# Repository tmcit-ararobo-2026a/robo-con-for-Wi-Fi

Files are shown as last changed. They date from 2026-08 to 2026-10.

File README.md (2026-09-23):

# < robo-con-for-Wi-Fi >

<!-- 一行でプロジェクトを説明する -->
the code and pcb in this repository is wireless robot's controller.     

## 目次

1. [概要](#1-概要)
2. [ドキュメント](#2-ドキュメント)
3. [コントリビューション](#3-コントリビューション)
4. [ビルド・使い方](#4-ビルド使い方)
5. [システム構成](#5-システム構成)
6. [ライセンス](#6-ライセンス)

## 1. 概要

<!-- プロジェクトの目的・背景・解決する課題を記述 -->
ロボコンなどの会場のなかでは2.4GHzもしくは5GHzといった周波数帯は多くの場合かなり混雑していることが多い。    
こういった大会で無線による有利は勝敗に大きく作用するため、使用する周波数はできるだけ混雑していないことが望ましい。  
そのため、6GHzを使うコントローラーを作成する。  

## 2. ドキュメント

| ドキュメント | 説明 |
| :-: | :-: |
| [CONTRIBUTING.md](./CONTRIBUTING.md) | 開発フロー・コミット規約・コーディング規約 |
| [docs/coding-rules.md](./docs/coding-rules.md) | コーディング規約の詳細 |
| [docs/uml/](./docs/uml/) | UML図 |

## 3. コントリビューション

[CONTRIBUTING.md](./CONTRIBUTING.md) を参照してください。

## 4. ビルド・使い方

<!-- ビルドのやり方 -->
<!-- 使い方 -->

## 5. システム構成

<!-- ROS2ノード構成・STM32との通信方式・ハードウェア構成 等 -->
<!-- 依存クラスが3つ以上ある場合は docs/uml/ にUML図を作成し、ここにリンクする -->

## 6. ライセンス

本リポジトリは [MITライセンス](./LICENSE) のもとで公開されています。

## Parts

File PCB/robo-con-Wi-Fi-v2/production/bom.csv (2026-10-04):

Designator | Footprint | Quantity | Value | LCSC Part #
C12, C13, C14, C15, C16, C17, C18, C19, C28, C33, C50, C66, C68, C69, C70, C72, C73, C78 | 0402 | 18 | 0.1u
C30, C31 | 0402 | 2 | 2.2u
C34, C35 | 0402 | 2 | 18pF
C61, C71, C80 | 0402 | 3 | 1u
C62, C63, C64, C74, C75, C76, C77, C79, C81, C83 | 0402 | 10 | 4.7u
C65 | 0402 | 1 | 1n
C82 | 0603 | 1 | 10u
D1 | 0603 | 1 | R
D10, D13, D14, D17 | 0603 | 4 | O
D11, D12 | 0603 | 2 | W
D16, D3 | 0603 | 2 | G
D5 | 0603 | 1 | B
F1 | 0603 | 1 | FHC16322ADTP
J1 | PinSocket_1x04_P2.54mm_Vertical | 1 | Conn_01x04
J11, J3 | JST_ZH_B5B-ZR_1x05_P1.50mm_Vertical | 2 | Conn_01x05
J2 | SMA_Conn | 1 | SMA-J
J4, J6, J8, J9 | SolderWirePad_1x01_SMD_1.5x3mm | 4 | Conn_01x01
J5 | JST_PH_S2B-PH-K_1x02_P2.00mm_Horizontal | 1 | Conn_01x02
L1 | 1008 | 1 | 2.2u
R11, R2, R21, R25, R32, R33, R34, R35, R37, R38, R4, R43, R45, R46, R6 | 0402 | 15 | 1k
R23 | 0402 | 1 | 10k
R24 | 0603 | 1 | 2.2k
R26, R27 | 0603 | 2 | 1k
R3, R5 | 0402 | 2 | 22
R39, R40 | 0402 | 2 | 4.7k
R41 | 0603 | 1 | 100k
R44 | WA04X102 | 1 | WA04X102
SW1 | switch_TVAF06-A020B-R | 1 | SW_Push
SW3, SW4 | SKHHLPA010 | 2 | SW_Push
SW5 | 4MS1R202M6QES | 1 | SW_Push_SPDT
SW6, SW7 | 8MS8P1B05VS2QES-C13 | 2 | SW_Push_SPDT
U10 | SOT-23-5 | 1 | MCP73831-2-OT
U11, U15 | SOT-363_SC-70-6 | 2 | LM66100DCK
U18 | USB_C_Receptacle_Nelton_5077CR-16-SMC2-BK-TR | 1 | USB_Type-C
U2 | LBEE5HY2FY | 1 | LBEE5HY2FY
U3 | WDFN-12-1EP_3x3mm_P0.45mm_EP1.7x2.5mm | 1 | FT234XD
U4 | DFN-8-1EP_3x3mm_P0.65mm_EP1.55x2.4mm | 1 | MCP1727-1802xMF
U5, U7 | RKJXV122400R | 2 | RKJXV122400R
U6 | DFN-6-1EP_3x3mm_P0.95mm_EP1.7x2.6mm | 1 | LD39200PU33R
U8 | LQFP-64_10x10mm_P0.5mm | 1 | STM32H7A3RGTx
Y2 | XRCGB25M000FFS1AR0 | 1 | XRCGB25M000FFS1AR0

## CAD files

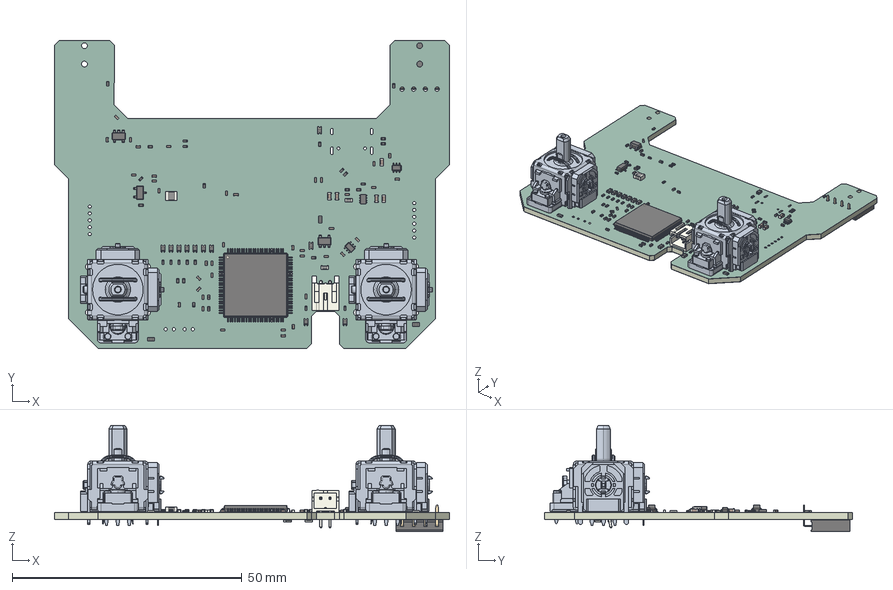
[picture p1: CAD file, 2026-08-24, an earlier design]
PCB/robo-con-Wi-Fi/動いたら使うやつ.step
86.0 x 67.0 x 23.2 mm
R_0402_1005Metric x 27
C_0402_1005Metric x 41
C_0603_1608Metric x 5
SC-59
D_0603_1608Metric x 11
SOT-583-8
R_0603_1608Metric x 5
.step 1.40 x 2
JST_PH_S2B-PH-K_1x02_P2.00mm_Horizontal
L_0603_1608Metric x 2
SOT-363_SC-70-6 x 2
L_1008_2520Metric
LQFP-100_14x14mm_P0.5mm
SOT-23-5 x 2
PinSocket_1x04_P2.54mm_Horizontal
robo-con-Wi-Fi_soldermask x 2
robo-con-Wi-Fi_PCB

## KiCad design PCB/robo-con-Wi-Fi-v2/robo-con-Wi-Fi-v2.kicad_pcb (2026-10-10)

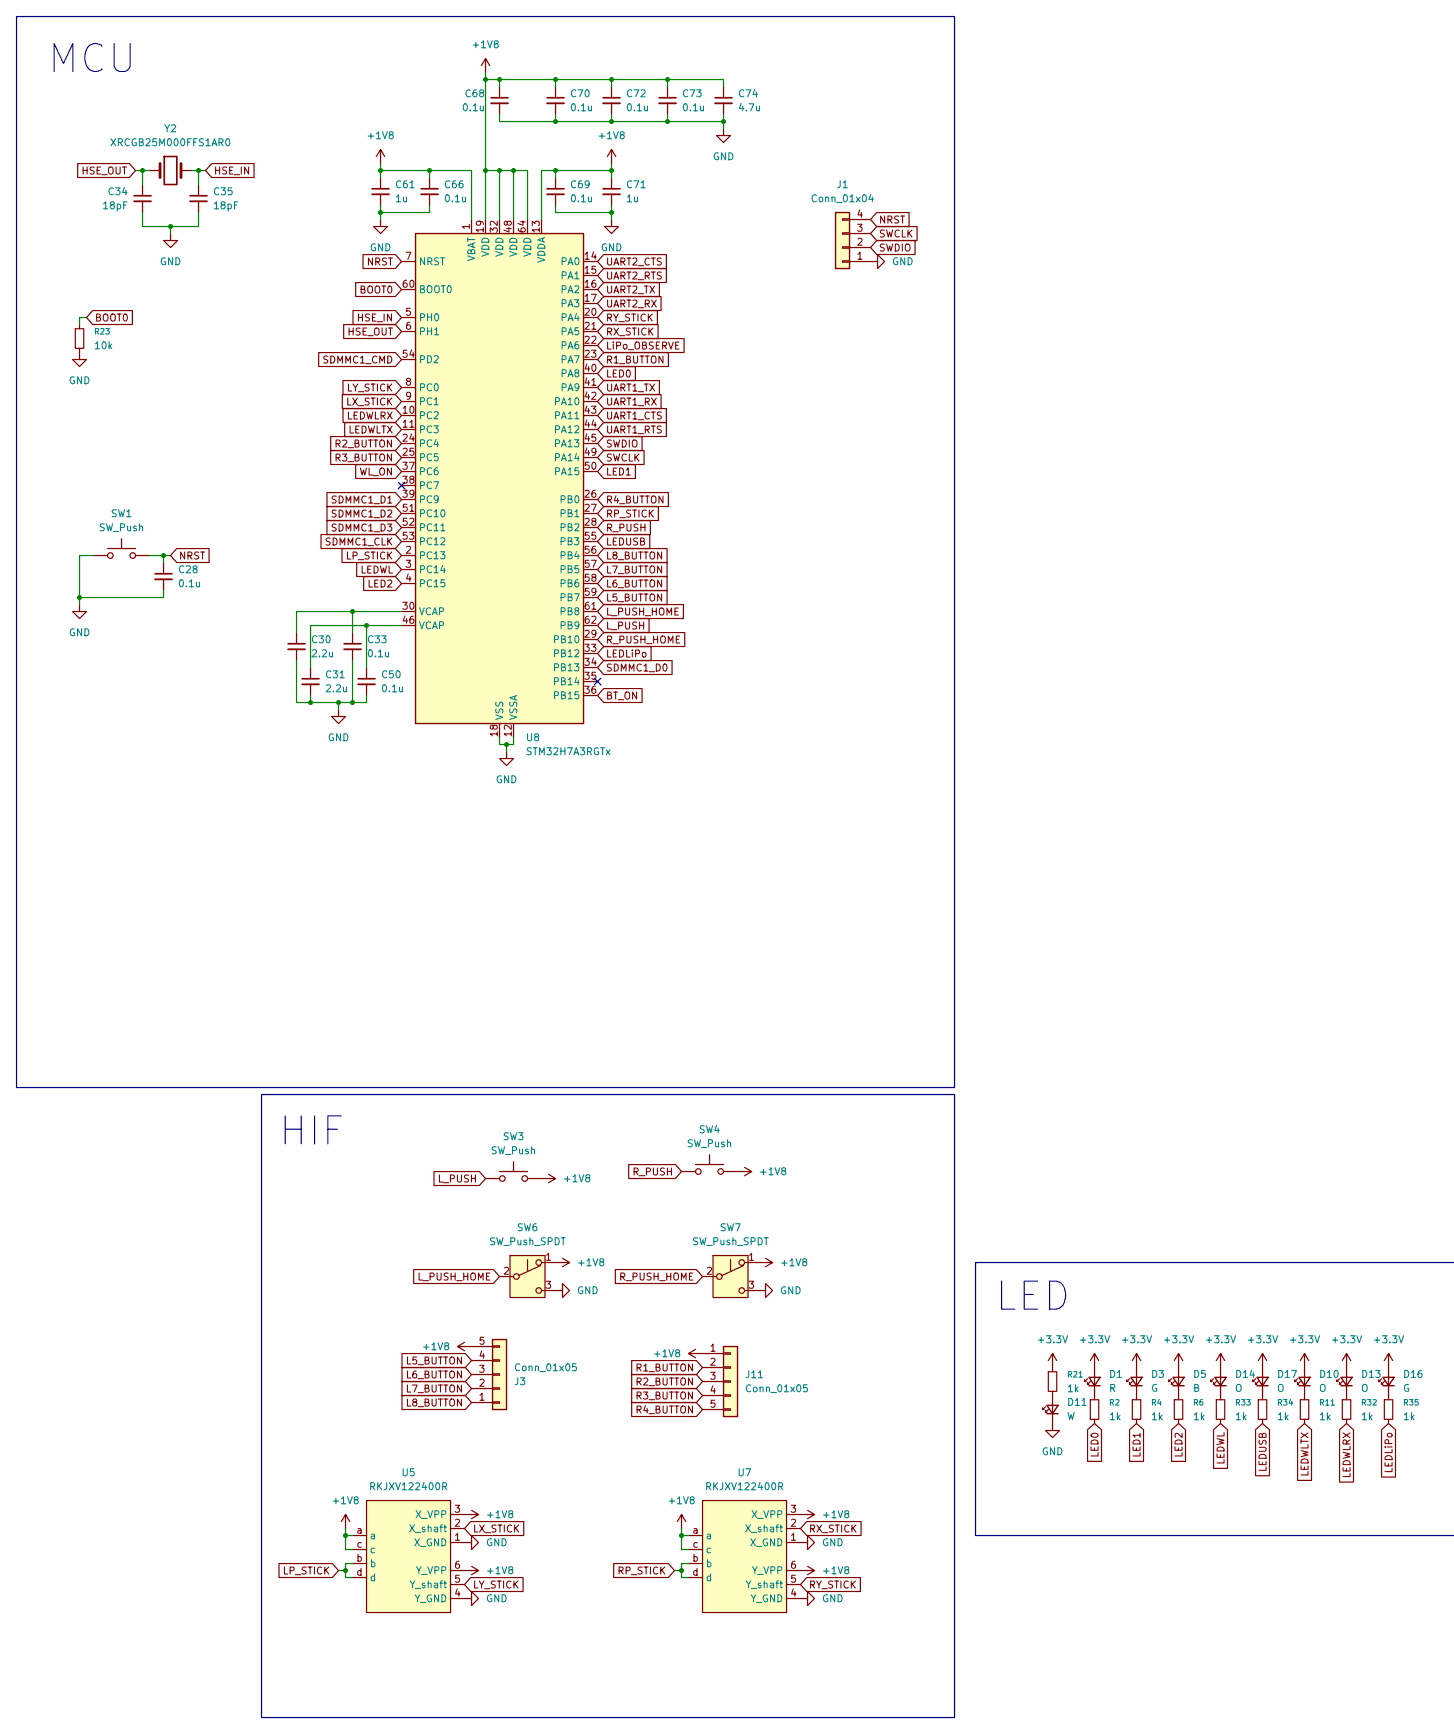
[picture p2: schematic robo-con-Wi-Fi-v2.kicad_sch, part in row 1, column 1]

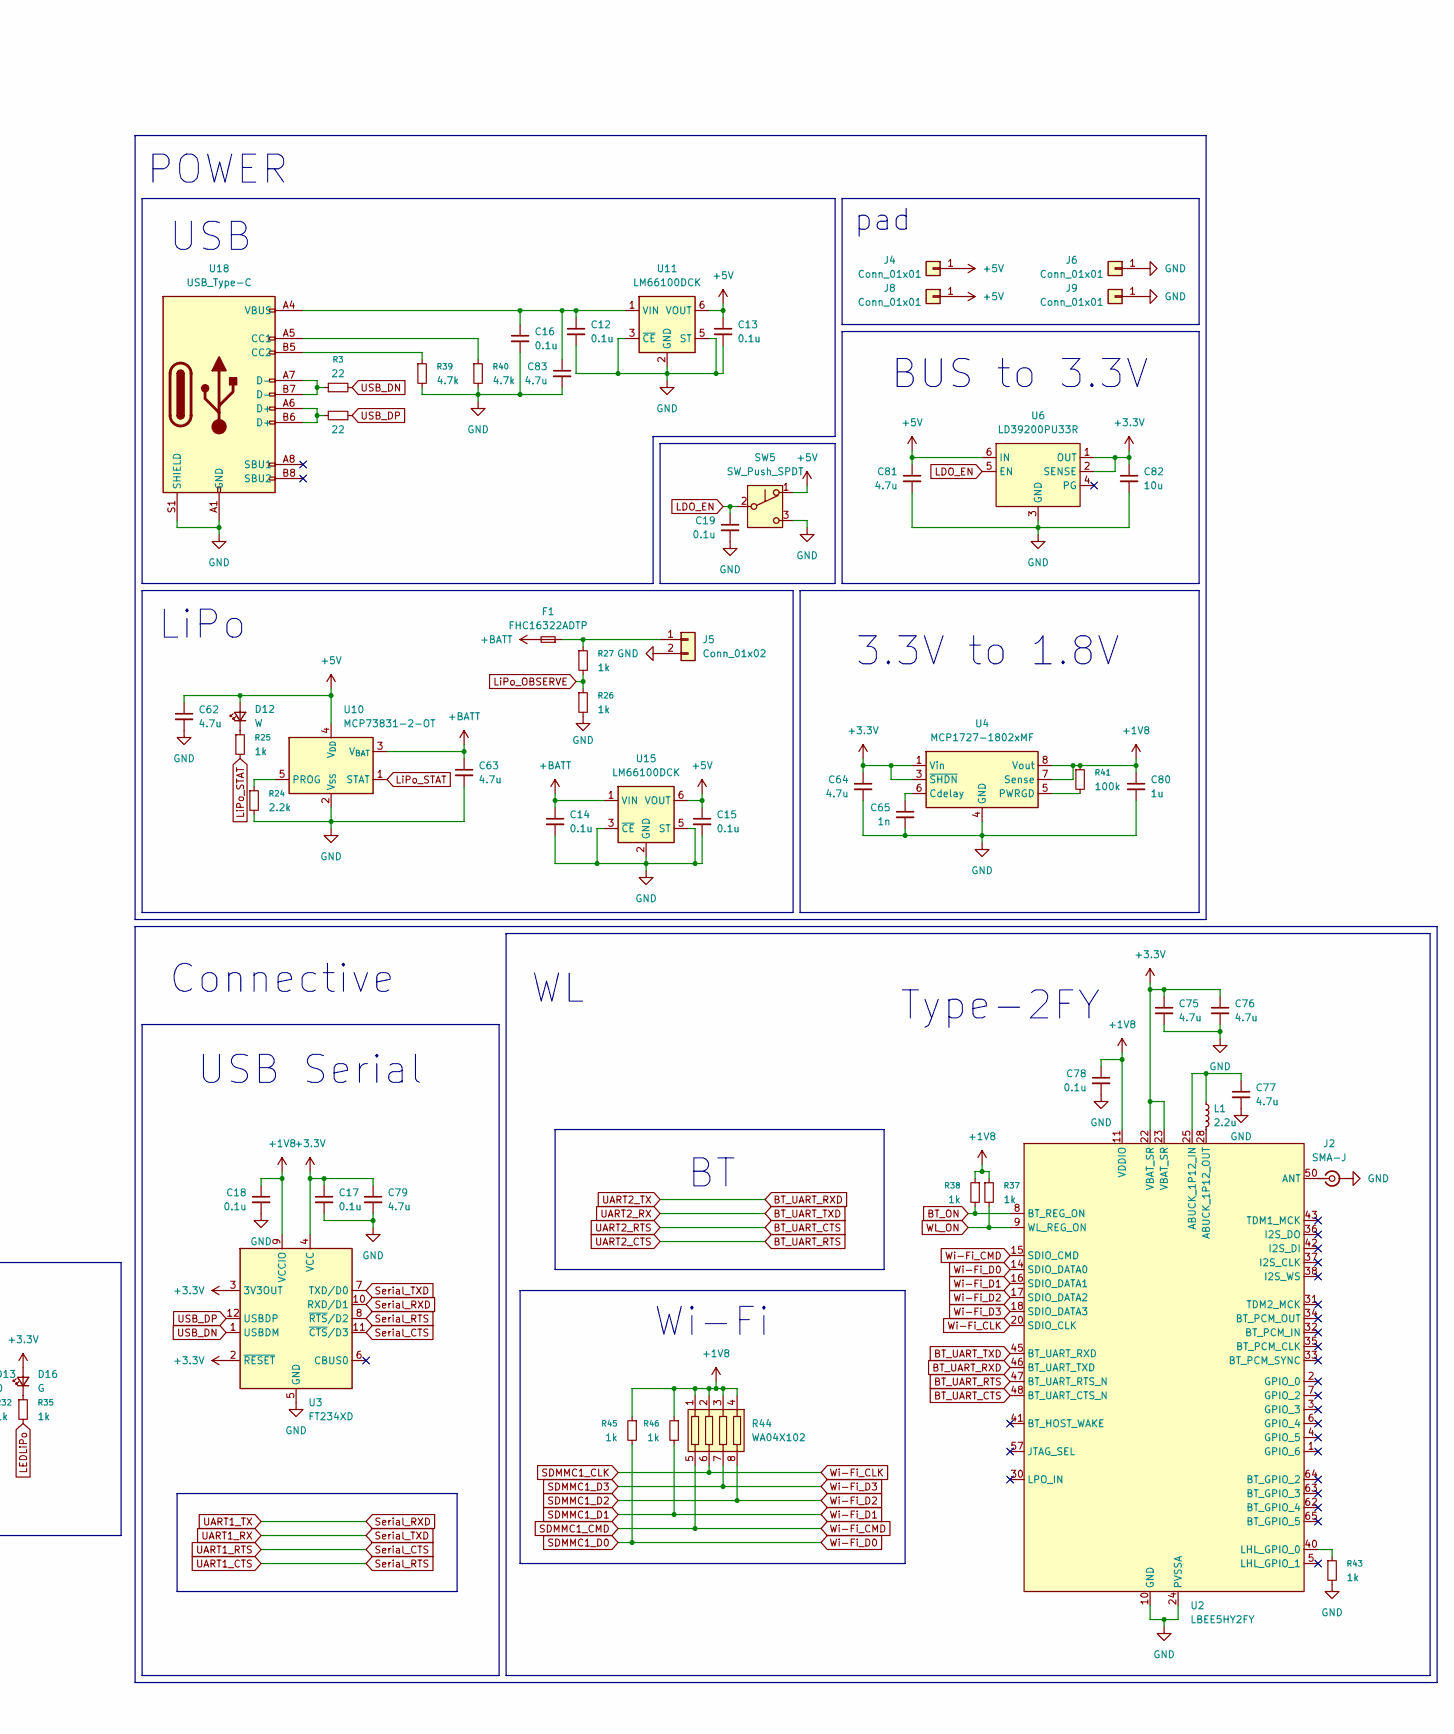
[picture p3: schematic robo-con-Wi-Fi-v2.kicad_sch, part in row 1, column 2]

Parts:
C12, C13, C14, C15, C16, C17, C18, C19, C28, C33, C50, C66, C68, C69, C70, C72, C73, C78: 0.1u; C_0402_1005Metric_Pad0.74x0.62mm_HandSolder
C30, C31: 2.2u; C_0402_1005Metric_Pad0.74x0.62mm_HandSolder
C34, C35: 18pF; C_0402_1005Metric_Pad0.74x0.62mm_HandSolder
C61, C71, C80: 1u; C_0402_1005Metric_Pad0.74x0.62mm_HandSolder
C62, C63, C64, C74, C75, C76, C77, C79, C81, C83: 4.7u; C_0402_1005Metric_Pad0.74x0.62mm_HandSolder
C65: 1n; C_0402_1005Metric_Pad0.74x0.62mm_HandSolder
C82: 10u; C_0603_1608Metric_Pad1.08x0.95mm_HandSolder
D1: R; D_0603_1608Metric_Pad1.05x0.95mm_HandSolder
D3, D16: G; D_0603_1608Metric_Pad1.05x0.95mm_HandSolder
D5: B; D_0603_1608Metric_Pad1.05x0.95mm_HandSolder
D10, D13, D14, D17: O; D_0603_1608Metric_Pad1.05x0.95mm_HandSolder
D11, D12: W; D_0603_1608Metric_Pad1.05x0.95mm_HandSolder
F1: FHC16322ADTP; L_0603_1608Metric_Pad1.05x0.95mm_HandSolder
J1: Conn_01x04; PinSocket_1x04_P2.54mm_Vertical
J2: SMA-J; SMA_Conn
J3, J11: Conn_01x05; JST_ZH_B5B-ZR_1x05_P1.50mm_Vertical
J4, J6, J8, J9: Conn_01x01; SolderWirePad_1x01_SMD_1.5x3mm
J5: Conn_01x02; JST_PH_S2B-PH-K_1x02_P2.00mm_Horizontal
L1: 2.2u; L_1008_2520Metric_Pad1.43x2.20mm_HandSolder
R2, R4, R6, R11, R21, R25, R32, R33, R34, R35, R37, R38, R43, R45, R46: 1k; R_0402_1005Metric_Pad0.72x0.64mm_HandSolder
R3, R5: 22; R_0402_1005Metric_Pad0.72x0.64mm_HandSolder
R23: 10k; R_0402_1005Metric_Pad0.72x0.64mm_HandSolder
R24: 2.2k; R_0603_1608Metric_Pad0.98x0.95mm_HandSolder
R26, R27: 1k; R_0603_1608Metric_Pad0.98x0.95mm_HandSolder
R39, R40: 4.7k; R_0402_1005Metric_Pad0.72x0.64mm_HandSolder
R41: 100k; R_0603_1608Metric_Pad0.98x0.95mm_HandSolder
R44: WA04X102
SW1: SW_Push; switch_TVAF06-A020B-R
SW3, SW4: SW_Push; SKHHLPA010
SW5: SW_Push_SPDT; 4MS1R202M6QES
SW6, SW7: SW_Push_SPDT; 8MS8P1B05VS2QES-C13
U2: LBEE5HY2FY
U3: FT234XD; WDFN-12-1EP_3x3mm_P0.45mm_EP1.7x2.5mm
U4: MCP1727-1802xMF; DFN-8-1EP_3x3mm_P0.65mm_EP1.55x2.4mm
U5, U7: RKJXV122400R
U6: LD39200PU33R; DFN-6-1EP_3x3mm_P0.95mm_EP1.7x2.6mm
U8: STM32H7A3RGTx; LQFP-64_10x10mm_P0.5mm
U10: MCP73831-2-OT; SOT-23-5
U11, U15: LM66100DCK; SOT-363_SC-70-6
U18: USB_Type-C; USB_C_Receptacle_Nelton_5077CR-16-SMC2-BK-TR
Y2: XRCGB25M000FFS1AR0

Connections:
+1V8: C18.1, C61.1, C66.1, C68.1, C69.1, C70.1, C71.1, C72.1, C73.1, C74.1, C78.1, C80.1, J3.5, J11.1, R37.1, R38.1, R41.1, R44.1, R44.2, R44.3, R44.4, R45.1, R46.1, SW3.2, SW4.2, SW6.1 (A), SW7.1 (A), U2.11 (VDDIO), U3.9 (VCCIO), U4.7 (Sense), U4.8 (Vout), U5.3 (X_VPP), U5.6 (Y_VPP), U5.a, U5.c, U7.3 (X_VPP), U7.6 (Y_VPP), U7.a, U7.c, U8.1 (VBAT), U8.13 (VDDA), U8.19 (VDD), U8.32 (VDD), U8.48 (VDD), U8.64 (VDD)
+3.3V: C17.1, C64.1, C75.1, C76.1, C79.1, C82.1, D1.2 (A), D3.2 (A), D5.2 (A), D10.2 (A), D13.2 (A), D14.2 (A), D16.2 (A), D17.2 (A), R21.1, U2.22 (VBAT_SR), U2.23 (VBAT_SR), U3.2 (~RESET), U3.3 (3V3OUT), U3.4 (VCC), U4.1 (Vin), U4.2 (Vin), U4.3 (~SHDN), U6.1 (OUT), U6.2 (SENSE)
+5V: C13.1, C15.1, C62.1, C81.1, D12.2 (A), J4.1 (Pin_1_1), J8.1 (Pin_1_1), SW5.1 (A), U6.6 (IN), U10.4 (V_{DD}), U11.6 (VOUT), U15.6 (VOUT)
+BATT: C14.1, C63.1, F1.2, U10.3 (V_{BAT}), U15.1 (VIN)
BOOT0: R23.1, U8.60 (BOOT0)
BT_ON: R38.2, U2.8 (BT_REG_ON), U8.36 (PB15)
BT_UART_CTS: U2.48 (BT_UART_CTS_N), U8.15 (PA1)
BT_UART_RTS: U2.47 (BT_UART_RTS_N), U8.14 (PA0)
BT_UART_RXD: U2.46 (BT_UART_TXD), U8.16 (PA2)
BT_UART_TXD: U2.45 (BT_UART_RXD), U8.17 (PA3)
GND: C12.2, C13.2, C14.2, C15.2, C16.2, C17.2, C18.2, C19.2, C28.2, C30.2, C31.2, C33.2, C34.2, C35.2, C50.2, C61.2, C62.2, C63.2, C64.2, C65.2, C66.2, C68.2, C69.2, C70.2, C71.2, C72.2, C73.2, C74.2, C75.2, C76.2, C77.2, C78.2, C79.2, C80.2, C81.2, C82.2, C83.2, D11.1 (K), J1.1, J2.2 (Ext), J5.2, J6.1 (Pin_1_1), J9.1 (Pin_1_1), R23.2, R24.2, R26.2, R39.2, R40.2, R43.2, SW1.1, SW5.3 (C), SW6.3 (C), SW7.3 (C), U2.10 (GND), U2.12 (GND), U2.13 (GND), U2.19 (GND), U2.21 (GND), U2.24 (PVSSA), U2.26 (PVSSA), U2.27 (PVSSA), U2.29 (GND), U2.39 (GND), U2.44 (GND), U2.49 (GND), U2.51 (GND), U2.52 (GND), U2.53 (GND), U2.55 (GND), U2.56 (GND), U2.58 (GND), U2.59 (GND), U2.60 (GND), U2.61 (GND), U2.66 (GND), U2.67 (GND), U2.68 (GND), U2.69 (GND), U2.70 (GND), U2.71 (GND), U2.72 (GND), U3.5 (GND), U3.13 (GND), U4.4 (GND), U4.9 (GND), U5.1 (X_GND), U5.4 (Y_GND), U6.3 (GND), U6.7 (GND), U7.1 (X_GND), U7.4 (Y_GND), U8.12 (VSSA), U8.18 (VSS), U8.31 (VSS), U8.47 (VSS), U8.63 (VSS), U10.2 (V_{SS}), U11.2 (GND), U11.3 (~CE), U11.5 (ST), U15.2 (GND), U15.3 (~CE), U15.5 (ST), U18.A1 (GND), U18.B1 (GND), U18.S1 (SHIELD)
HSE_IN: C35.1, U8.5 (PH0), Y2.3 (2)
HSE_OUT: C34.1, U8.6 (PH1), Y2.1
L5_BUTTON: J3.4, U8.59 (PB7)
L6_BUTTON: J3.3, U8.58 (PB6)
L7_BUTTON: J3.2, U8.57 (PB5)
L8_BUTTON: J3.1, U8.56 (PB4)
LDO_EN: C19.1, SW5.2 (B), U6.5 (EN)
LED0: R2.2, U8.40 (PA8)
LED1: R4.2, U8.50 (PA15)
LED2: R6.2, U8.4 (PC15)
LEDLiPo: R35.2, U8.33 (PB12)
LEDUSB: R34.2, U8.55 (PB3)
LEDWL: R33.2, U8.3 (PC14)
LEDWLRX: R32.2, U8.10 (PC2)
LEDWLTX: R11.2, U8.11 (PC3)
LP_STICK: U5.b, U5.d, U8.2 (PC13)
LX_STICK: U5.2 (X_shaft), U8.9 (PC1)
LY_STICK: U5.5 (Y_shaft), U8.8 (PC0)
L_PUSH: SW3.1, U8.62 (PB9)
L_PUSH_HOME: SW6.2 (B), U8.61 (PB8)
LiPo_OBSERVE: R26.1, R27.2, U8.22 (PA6)
LiPo_STAT: R25.2, U10.1 (STAT)
NRST: C28.1, J1.4, SW1.2, U8.7 (NRST)
unnamed: C30.1, C33.1, U8.30 (VCAP)
unnamed: C31.1, C50.1, U8.46 (VCAP)
unnamed: D1.1 (K), R2.1
unnamed: D3.1 (K), R4.1
unnamed: D5.1 (K), R6.1
unnamed: D10.1 (K), R11.1
unnamed: D11.2 (A), R21.2
unnamed: D12.1 (K), R25.1
unnamed: D13.1 (K), R32.1
unnamed: D14.1 (K), R33.1
unnamed: D16.1 (K), R35.1
unnamed: D17.1 (K), R34.1
unnamed: J2.1 (In), U2.50 (ANT)
unnamed: F1.1, J5.1, R27.1
unnamed: R3.1, U18.A7 (D-), U18.B7 (D-)
unnamed: R5.1, U18.A6 (D+), U18.B6 (D+)
unnamed: C77.1, L1.1, U2.25 (ABUCK_1P12_IN)
unnamed: L1.2, U2.28 (ABUCK_1P12_OUT)
unnamed: R43.1, U2.40 (LHL_GPIO_0)
unnamed: C65.1, U4.6 (Cdelay)
unnamed: R41.2, U4.5 (PWRGD)
unnamed: R24.1, U10.5 (PROG)
unnamed: C12.1, C16.1, C83.1, U11.1 (VIN), U18.A4 (VBUS), U18.B4 (VBUS)
unnamed: R40.1, U18.A5 (CC1)
unnamed: R39.1, U18.B5 (CC2)
R1_BUTTON: J11.2, U8.23 (PA7)
R2_BUTTON: J11.3, U8.24 (PC4)
R3_BUTTON: J11.4, U8.25 (PC5)
R4_BUTTON: J11.5, U8.26 (PB0)
RP_STICK: U7.b, U7.d, U8.27 (PB1)
RX_STICK: U7.2 (X_shaft), U8.21 (PA5)
RY_STICK: U7.5 (Y_shaft), U8.20 (PA4)
R_PUSH: SW4.1, U8.28 (PB2)
R_PUSH_HOME: SW7.2 (B), U8.29 (PB10)
SDMMC1_CLK: R44.6, U2.20 (SDIO_CLK), U8.53 (PC12)
SDMMC1_CMD: R44.5, U2.15 (SDIO_CMD), U8.54 (PD2)
SDMMC1_D0: R45.2, U2.14 (SDIO_DATA0), U8.34 (PB13)
SDMMC1_D1: R46.2, U2.16 (SDIO_DATA1), U8.39 (PC9)
SDMMC1_D2: R44.8, U2.17 (SDIO_DATA2), U8.51 (PC10)
SDMMC1_D3: R44.7, U2.18 (SDIO_DATA3), U8.52 (PC11)
SWCLK: J1.3, U8.49 (PA14)
SWDIO: J1.2, U8.45 (PA13)
Serial_CTS: U3.11 (~CTS/D3), U8.44 (PA12)
Serial_RTS: U3.8 (~RTS/D2), U8.43 (PA11)
Serial_RXD: U3.10 (RXD/D1), U8.41 (PA9)
Serial_TXD: U3.7 (TXD/D0), U8.42 (PA10)
USB_DN: R3.2, U3.1 (USBDM)
USB_DP: R5.2, U3.12 (USBDP)
WL_ON: R37.2, U2.9 (WL_REG_ON), U8.37 (PC6)

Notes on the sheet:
Connective
pad
Type-2FY
USB Serial
USB
LiPo
BUS to 3.3V
Wi-Fi
POWER
LED
3.3V to 1.8V
MCU
HIF

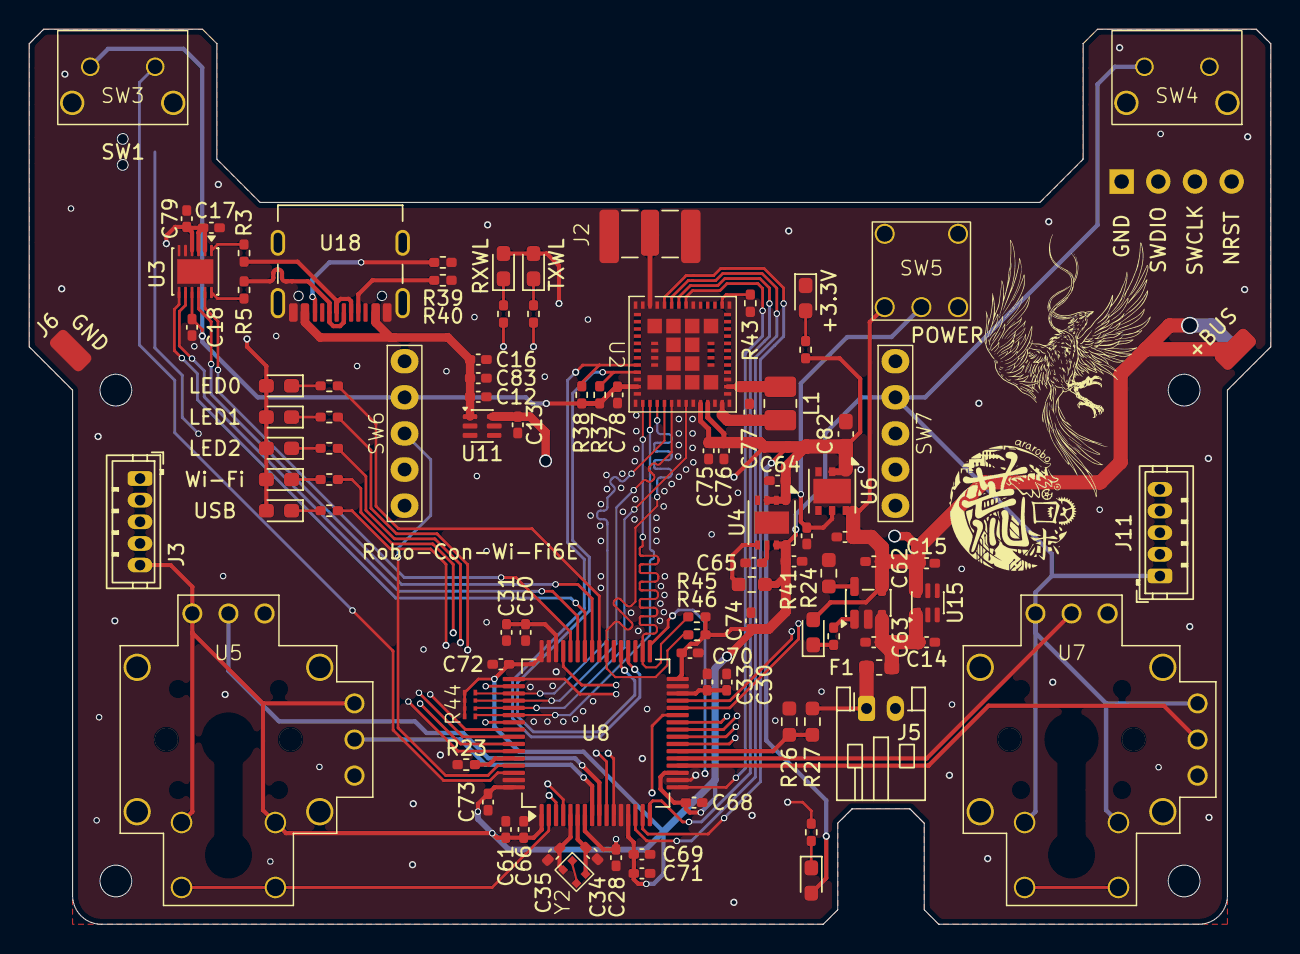
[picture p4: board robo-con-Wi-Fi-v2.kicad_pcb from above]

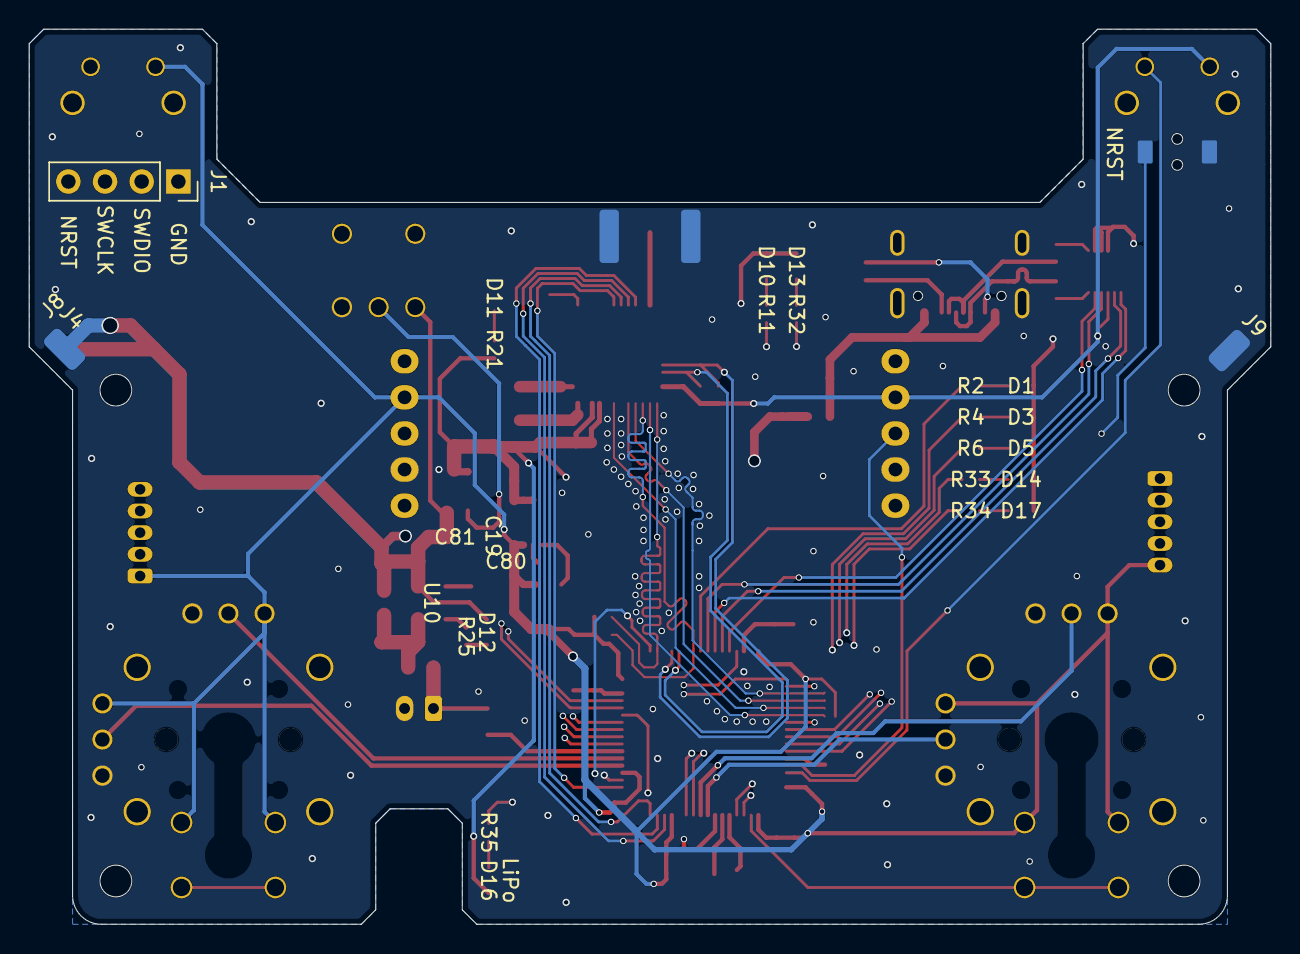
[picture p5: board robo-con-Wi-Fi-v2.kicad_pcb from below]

Board: 4 copper layers, 86.0 x 62.0 mm, 101 parts (4 on the bottom side), 83 nets.

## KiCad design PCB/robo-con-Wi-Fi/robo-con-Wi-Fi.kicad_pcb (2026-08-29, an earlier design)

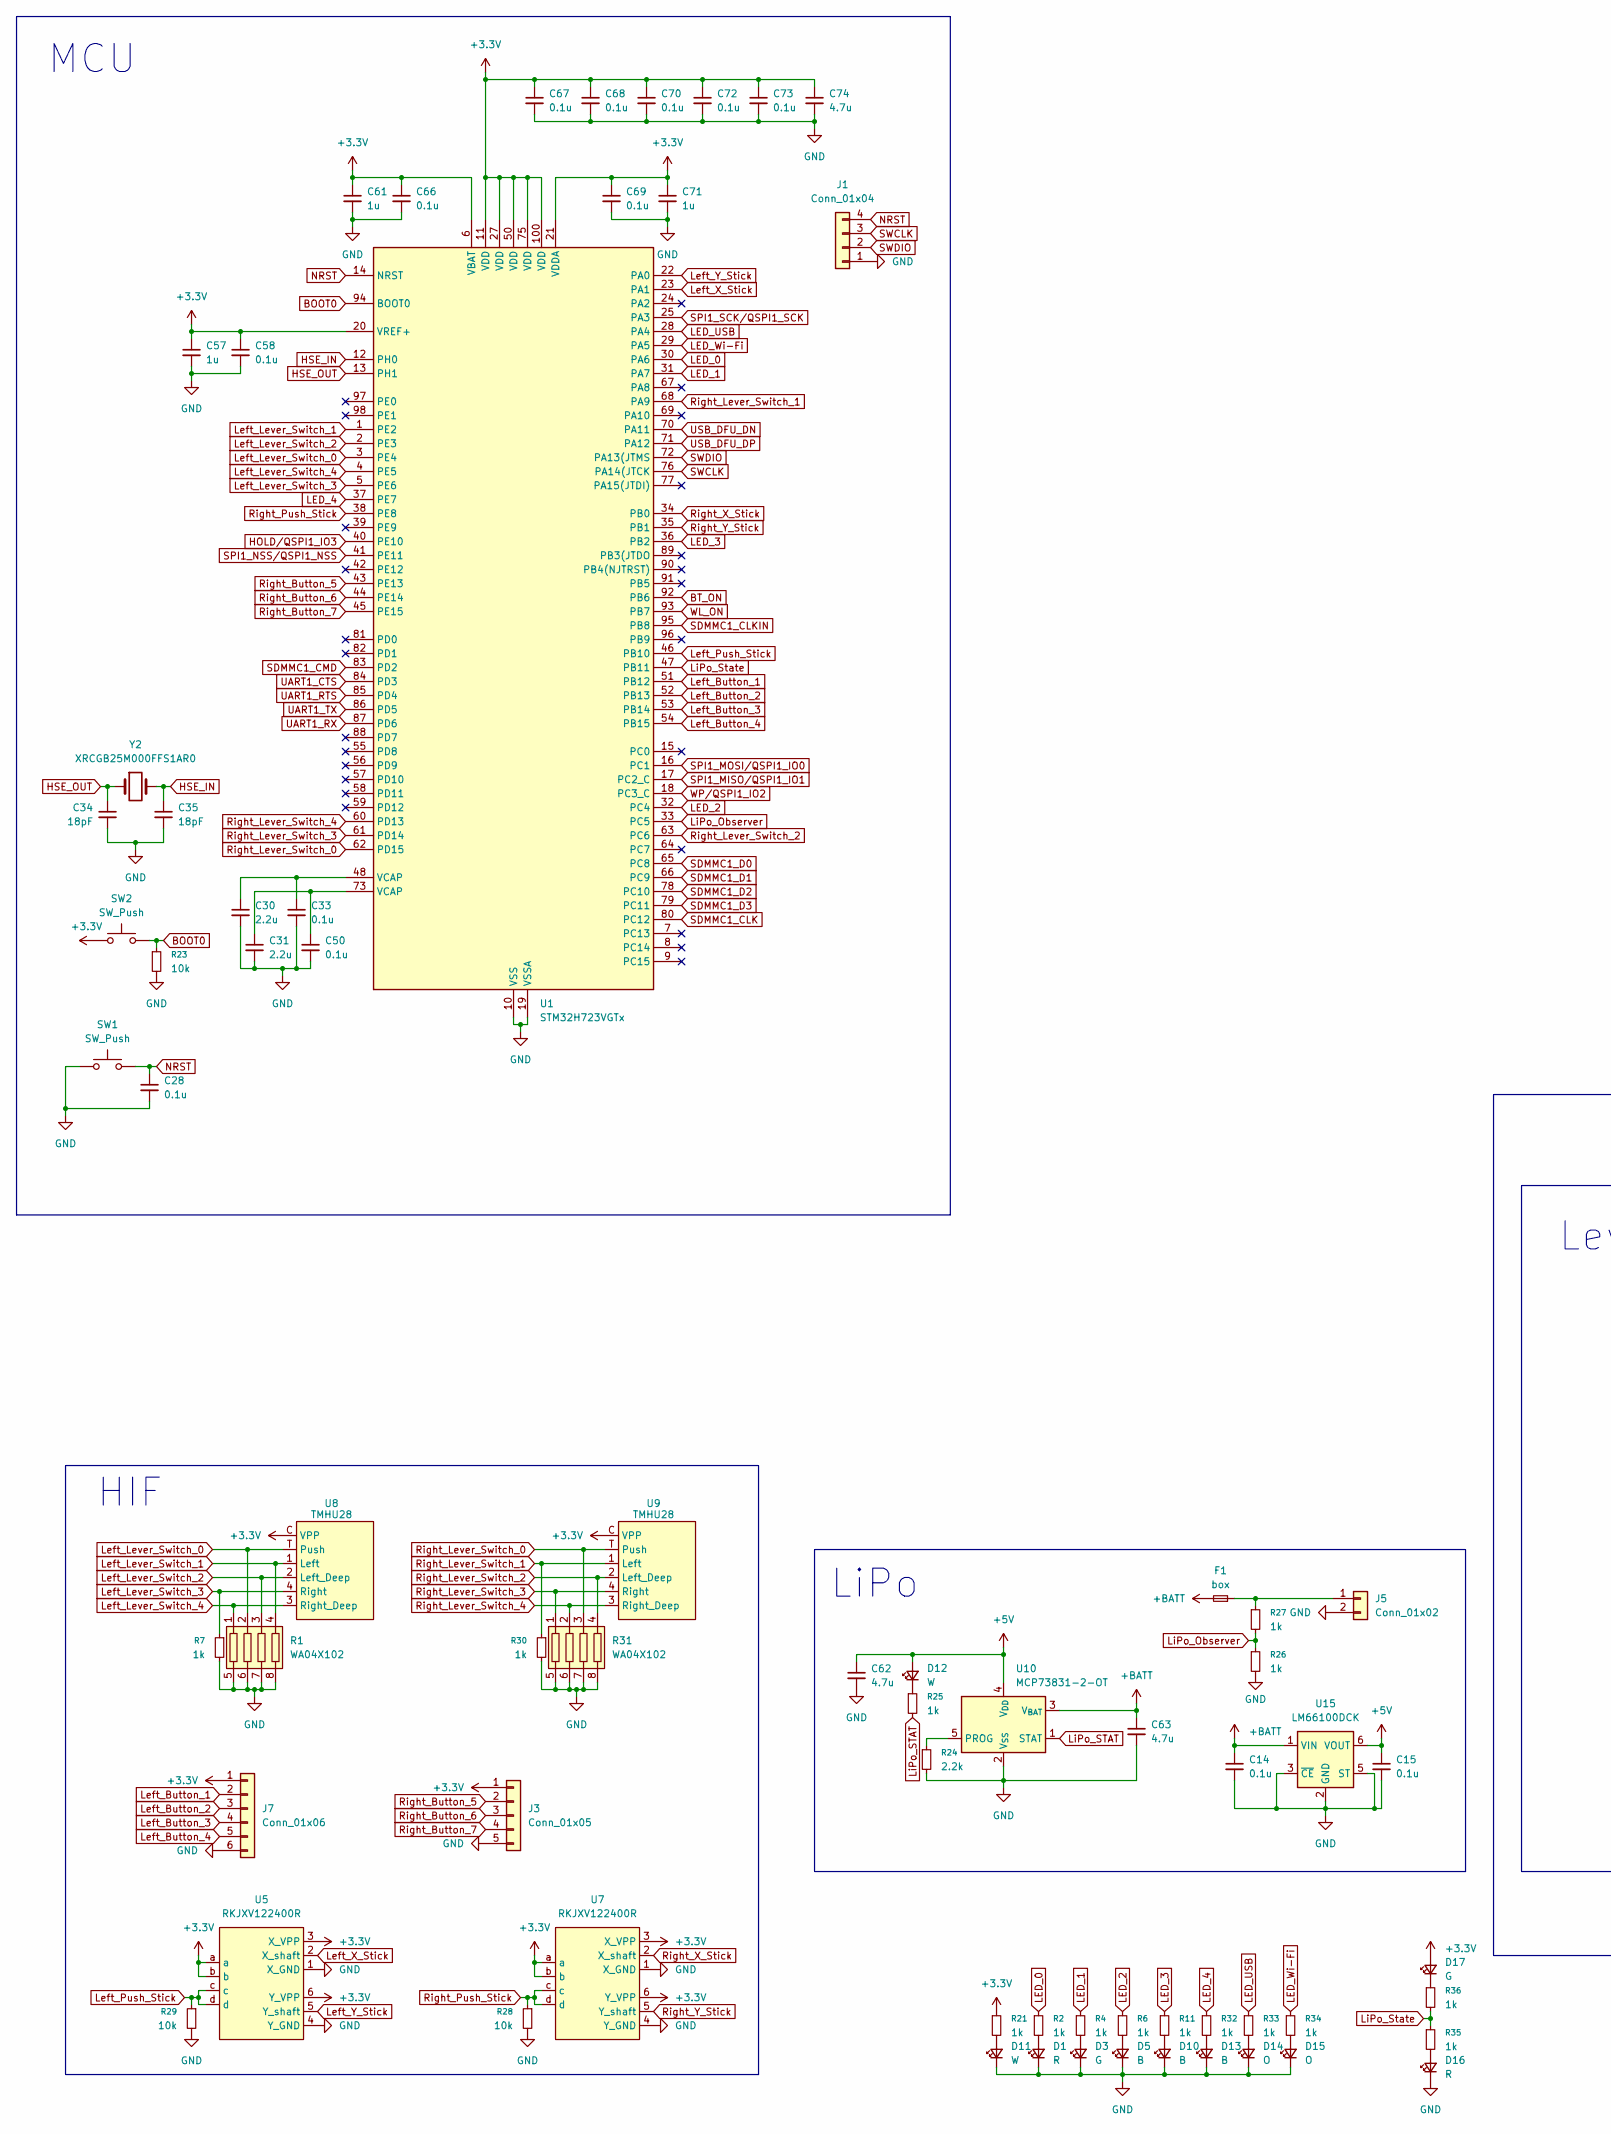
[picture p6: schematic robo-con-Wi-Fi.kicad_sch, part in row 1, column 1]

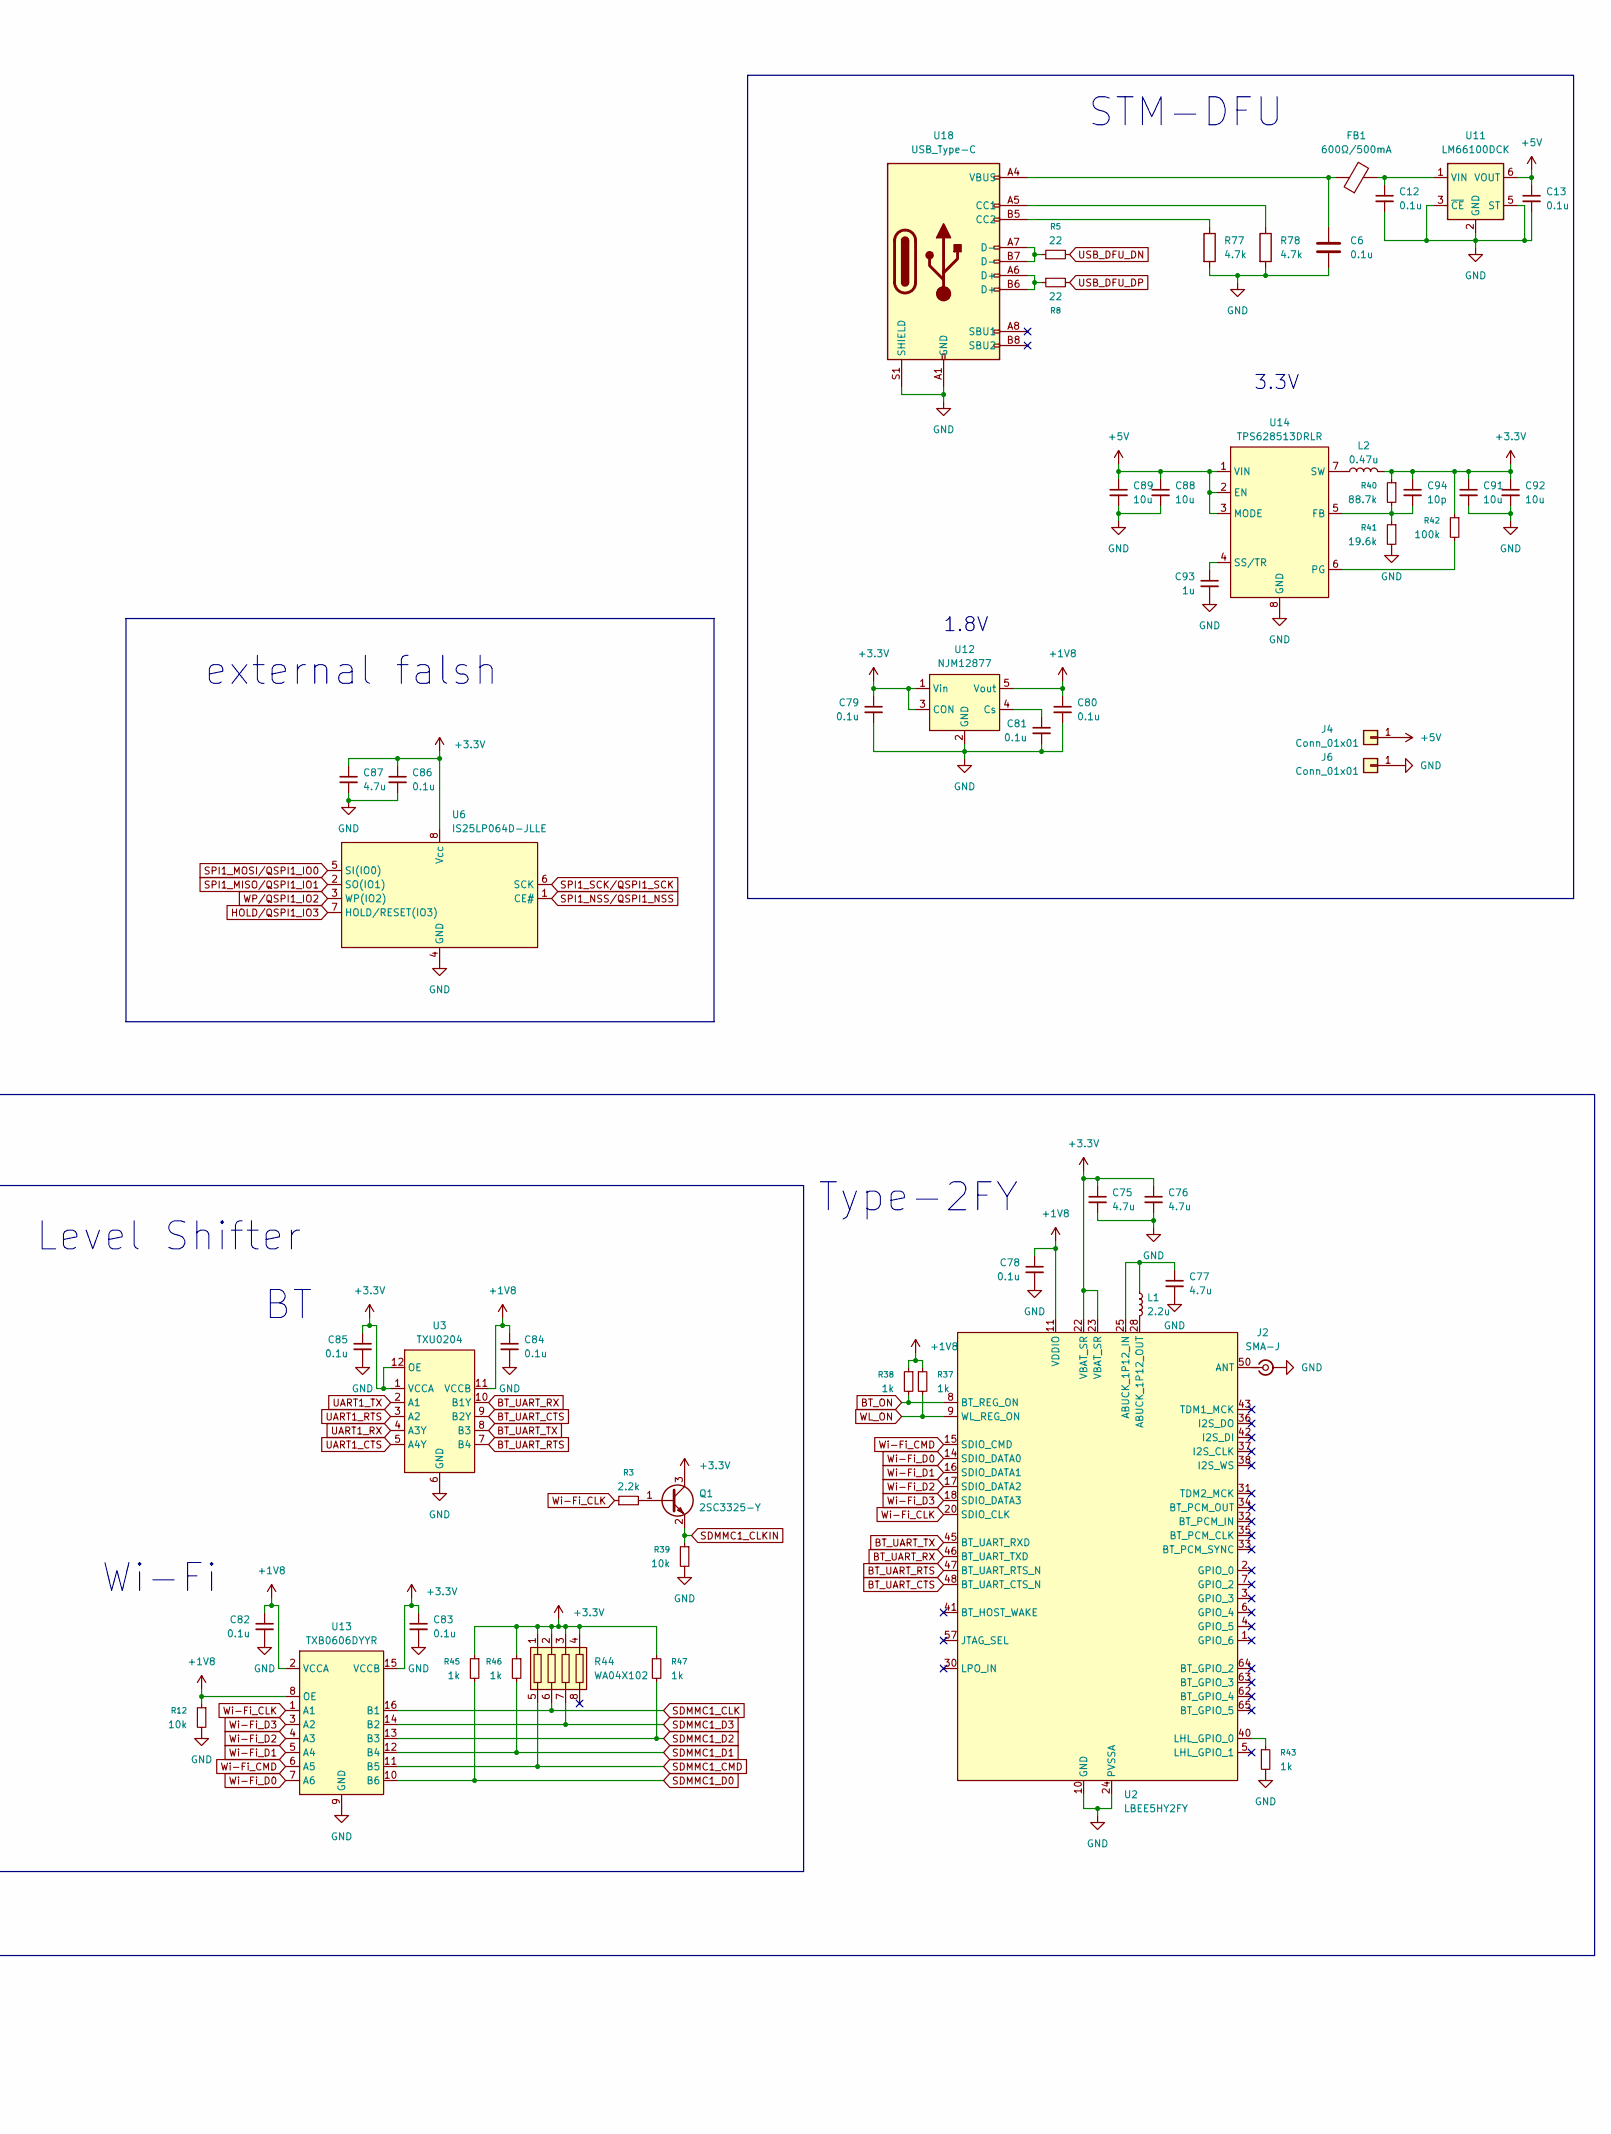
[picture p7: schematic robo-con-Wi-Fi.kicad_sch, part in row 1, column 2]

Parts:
C6, C12, C13, C14, C15, C28, C33, C50, C58, C66, C67, C68, C69, C70, C72, C73, C78, C79, C80, C81, C82, C83, C84, C85, C86: 0.1u; C_0402_1005Metric_Pad0.74x0.62mm_HandSolder
C30, C31: 2.2u; C_0402_1005Metric_Pad0.74x0.62mm_HandSolder
C34, C35: 18pF; C_0402_1005Metric_Pad0.74x0.62mm_HandSolder
C57, C61, C71, C93: 1u; C_0402_1005Metric_Pad0.74x0.62mm_HandSolder
C62, C63, C74, C75, C76, C77, C87: 4.7u; C_0402_1005Metric_Pad0.74x0.62mm_HandSolder
C88, C89, C91, C92: 10u; C_0603_1608Metric_Pad1.08x0.95mm_HandSolder
C94: 10p; C_0402_1005Metric_Pad0.74x0.62mm_HandSolder
D1, D16: R; D_0603_1608Metric_Pad1.05x0.95mm_HandSolder
D3, D17: G; D_0603_1608Metric_Pad1.05x0.95mm_HandSolder
D5, D10, D13: B; D_0603_1608Metric_Pad1.05x0.95mm_HandSolder
D11, D12: W; D_0603_1608Metric_Pad1.05x0.95mm_HandSolder
D14, D15: O; D_0603_1608Metric_Pad1.05x0.95mm_HandSolder
F1: box; L_0603_1608Metric_Pad1.05x0.95mm_HandSolder
FB1: 600Ω/500mA; C_0603_1608Metric_Pad1.08x0.95mm_HandSolder
J1: Conn_01x04; PinSocket_1x04_P2.54mm_Horizontal
J2: SMA-J; SMA_Conn
J3: Conn_01x05; JST_ZH_B5B-ZR_1x05_P1.50mm_Vertical
J4, J6: Conn_01x01; SolderWirePad_1x01_SMD_1.5x3mm
J5: Conn_01x02; JST_PH_S2B-PH-K_1x02_P2.00mm_Horizontal
J7: Conn_01x06; JST_ZH_B6B-ZR_1x06_P1.50mm_Vertical
L1: 2.2u; L_1008_2520Metric_Pad1.43x2.20mm_HandSolder
L2: 0.47u; L_0603_1608Metric_Pad1.05x0.95mm_HandSolder
Q1: 2SC3325-Y; SC-59
R1, R31, R44: WA04X102
R2, R4, R6, R7, R11, R21, R25, R30, R32, R33, R34, R35, R36, R37, R38, R43, R45, R46, R47: 1k; R_0402_1005Metric_Pad0.72x0.64mm_HandSolder
R3: 2.2k; R_0402_1005Metric_Pad0.72x0.64mm_HandSolder
R5, R8: 22; R_0402_1005Metric_Pad0.72x0.64mm_HandSolder
R12, R23, R39: 10k; R_0402_1005Metric_Pad0.72x0.64mm_HandSolder
R24: 2.2k; R_0603_1608Metric_Pad0.98x0.95mm_HandSolder
R26, R27: 1k; R_0603_1608Metric_Pad0.98x0.95mm_HandSolder
R28, R29: 10k; R_0603_1608Metric_Pad0.98x0.95mm_HandSolder
R40: 88.7k; R_0402_1005Metric_Pad0.72x0.64mm_HandSolder
R41: 19.6k; R_0402_1005Metric_Pad0.72x0.64mm_HandSolder
R42: 100k; R_0402_1005Metric_Pad0.72x0.64mm_HandSolder
R77, R78: 4.7k; R_0402_1005Metric_Pad0.72x0.64mm_HandSolder
SW1, SW2: SW_Push; switch_TVAF06-A020B-R
U1: STM32H723VGTx; LQFP-100_14x14mm_P0.5mm
U2: LBEE5HY2FY
U3: TXU0204; UQFN-12
U5, U7: RKJXV122400R
U6: IS25LP064D-JLLE; WSON-8-1EP_8x6mm_P1.27mm_EP3.4x4.3mm
U8, U9: TMHU28
U10: MCP73831-2-OT; SOT-23-5
U11, U15: LM66100DCK; SOT-363_SC-70-6
U12: NJM12877; SOT-23-5_HandSoldering
U13: TXB0606DYYR; Texas_DYY0016A_TSOT-23-16_2x4.2mm_P0.5mm
U14: TPS628513DRLR; SOT-583-8
U18: USB_Type-C; USB_C_Receptacle_Nelton_5077CR-16-SMC2-BK-TR
Y2: XRCGB25M000FFS1AR0

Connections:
+1V8: C78.1, C80.1, C82.1, C84.1, R12.1, R37.1, R38.1, U2.11 (VDDIO), U3.11 (VCCB), U12.5 (Vout), U13.2 (VCCA), U13.8 (OE)
+3.3V: C57.1, C58.1, C61.1, C66.1, C67.1, C68.1, C69.1, C70.1, C71.1, C72.1, C73.1, C74.1, C75.1, C76.1, C79.1, C83.1, C85.1, C86.1, C87.1, C91.1, C92.1, C94.1, D17.2 (A), J3.1, J7.1, L2.2, Q1.3 (C), R21.1, R40.1, R42.1, R44.1, R44.2, R44.3, R44.4, R45.1, R46.1, R47.1, SW2.1, U1.6 (VBAT), U1.11 (VDD), U1.20 (VREF+), U1.21 (VDDA), U1.27 (VDD), U1.50 (VDD), U1.75 (VDD), U1.100 (VDD), U2.22 (VBAT_SR), U2.23 (VBAT_SR), U3.1 (VCCA), U3.12 (OE), U5.3 (X_VPP), U5.6 (Y_VPP), U5.a, U5.b, U6.8 (Vcc), U7.3 (X_VPP), U7.6 (Y_VPP), U7.a, U7.b, U8.C (VPP), U9.C (VPP), U12.1 (Vin), U12.3 (CON), U13.15 (VCCB)
+5V: C13.1, C15.1, C62.1, C88.1, C89.1, D12.2 (A), J4.1 (Pin_1_1), U10.4 (V_{DD}), U11.6 (VOUT), U14.1 (VIN), U14.2 (EN), U14.3 (MODE), U15.6 (VOUT)
+BATT: C14.1, C63.1, F1.2, U10.3 (V_{BAT}), U15.1 (VIN)
BOOT0: R23.1, SW2.2, U1.94 (BOOT0)
BT_ON: R38.2, U1.92 (PB6), U2.8 (BT_REG_ON)
BT_UART_CTS: U2.48 (BT_UART_CTS_N), U3.9 (B2Y)
BT_UART_RTS: U2.47 (BT_UART_RTS_N), U3.7 (B4)
BT_UART_RX: U2.46 (BT_UART_TXD), U3.10 (B1Y)
BT_UART_TX: U2.45 (BT_UART_RXD), U3.8 (B3)
GND: C6.2, C12.2, C13.2, C14.2, C15.2, C28.2, C30.2, C31.2, C33.2, C34.2, C35.2, C50.2, C57.2, C58.2, C61.2, C62.2, C63.2, C66.2, C67.2, C68.2, C69.2, C70.2, C71.2, C72.2, C73.2, C74.2, C75.2, C76.2, C77.2, C78.2, C79.2, C80.2, C81.2, C82.2, C83.2, C84.2, C85.2, C86.2, C87.2, C88.2, C89.2, C91.2, C92.2, C93.2, D1.1 (K), D3.1 (K), D5.1 (K), D10.1 (K), D11.1 (K), D13.1 (K), D14.1 (K), D15.1 (K), D16.1 (K), J1.1, J2.2 (Ext), J3.5, J5.2, J6.1 (Pin_1_1), J7.6, R1.5, R1.6, R1.7, R1.8, R7.2, R12.2, R23.2, R24.2, R26.2, R28.2, R29.2, R30.2, R31.5, R31.6, R31.7, R31.8, R39.2, R41.2, R43.2, R77.2, R78.2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
HOLD/QSPI1_IO3: U1.40 (PE10), U6.7 (HOLD/RESET(IO3))
HSE_IN: C35.1, U1.12 (PH0), Y2.3 (2)
HSE_OUT: C34.1, U1.13 (PH1), Y2.1
LED_0: R2.1, U1.30 (PA6)
LED_1: R4.1, U1.31 (PA7)
LED_2: R6.1, U1.32 (PC4)
LED_3: R11.1, U1.36 (PB2)
LED_4: R32.1, U1.37 (PE7)
LED_USB: R33.1, U1.28 (PA4)
LED_Wi-Fi: R34.1, U1.29 (PA5)
Left_Button_1: J7.2, U1.51 (PB12)
Left_Button_2: J7.3, U1.52 (PB13)
Left_Button_3: J7.4, U1.53 (PB14)
Left_Button_4: J7.5, U1.54 (PB15)
Left_Lever_Switch_0: R1.2, U1.3 (PE4), U8.T (Push)
Left_Lever_Switch_1: R1.4, U1.1 (PE2), U8.1 (Left)
Left_Lever_Switch_2: R1.3, U1.2 (PE3), U8.2 (Left_Deep)
Left_Lever_Switch_3: R7.1, U1.5 (PE6), U8.4 (Right)
Left_Lever_Switch_4: R1.1, U1.4 (PE5), U8.3 (Right_Deep)
Left_Push_Stick: R29.1, U1.46 (PB10), U5.c, U5.d
Left_X_Stick: U1.23 (PA1), U5.2 (X_shaft)
Left_Y_Stick: U1.22 (PA0), U5.5 (Y_shaft)
LiPo_Observer: R26.1, R27.2, U1.33 (PC5)
LiPo_STAT: R25.2, U10.1 (STAT)
LiPo_State: R35.1, R36.2, U1.47 (PB11)
NRST: C28.1, J1.4, SW1.2, U1.14 (NRST)
unnamed: C6.1, FB1.1, U18.A4 (VBUS), U18.B4 (VBUS)
unnamed: C30.1, C33.1, U1.48 (VCAP)
unnamed: C31.1, C50.1, U1.73 (VCAP)
unnamed: D1.2 (A), R2.2
unnamed: D3.2 (A), R4.2
unnamed: D5.2 (A), R6.2
unnamed: D10.2 (A), R11.2
unnamed: D11.2 (A), R21.2
unnamed: D12.1 (K), R25.1
unnamed: D13.2 (A), R32.2
unnamed: D14.2 (A), R33.2
unnamed: D15.2 (A), R34.2
unnamed: D16.2 (A), R35.2
unnamed: D17.1 (K), R36.1
unnamed: J2.1 (In), U2.50 (ANT)
unnamed: F1.1, J5.1, R27.1
unnamed: Q1.1 (B), R3.2
unnamed: R5.1, U18.A7 (D-), U18.B7 (D-)
unnamed: R8.1, U18.A6 (D+), U18.B6 (D+)
unnamed: C77.1, L1.1, U2.25 (ABUCK_1P12_IN)
unnamed: L1.2, U2.28 (ABUCK_1P12_OUT)
unnamed: R43.1, U2.40 (LHL_GPIO_0)
unnamed: R24.1, U10.5 (PROG)
unnamed: C12.1, FB1.2, U11.1 (VIN)
unnamed: C81.1, U12.4 (Cs)
unnamed: C94.2, R40.2, R41.1, U14.5 (FB)
unnamed: R42.2, U14.6 (PG)
unnamed: C93.1, U14.4 (SS/TR)
unnamed: L2.1, U14.7 (SW)
unnamed: R78.1, U18.A5 (CC1)
unnamed: R77.1, U18.B5 (CC2)
Right_Button_5: J3.2, U1.43 (PE13)
Right_Button_6: J3.3, U1.44 (PE14)
Right_Button_7: J3.4, U1.45 (PE15)
Right_Lever_Switch_0: R31.3, U1.62 (PD15), U9.T (Push)
Right_Lever_Switch_1: R30.1, U1.68 (PA9), U9.1 (Left)
Right_Lever_Switch_2: R31.4, U1.63 (PC6), U9.2 (Left_Deep)
Right_Lever_Switch_3: R31.1, U1.61 (PD14), U9.4 (Right)
Right_Lever_Switch_4: R31.2, U1.60 (PD13), U9.3 (Right_Deep)
Right_Push_Stick: R28.1, U1.38 (PE8), U7.c, U7.d
Right_X_Stick: U1.34 (PB0), U7.2 (X_shaft)
Right_Y_Stick: U1.35 (PB1), U7.5 (Y_shaft)
SDMMC1_CLK: R44.6, U1.80 (PC12), U13.16 (B1)
SDMMC1_CLKIN: Q1.2 (E), R39.1, U1.95 (PB8)
SDMMC1_CMD: R44.5, U1.83 (PD2), U13.11 (B5)
SDMMC1_D0: R45.2, U1.65 (PC8), U13.10 (B6)
SDMMC1_D1: R46.2, U1.66 (PC9), U13.12 (B4)
SDMMC1_D2: R47.2, U1.78 (PC10), U13.13 (B3)
SDMMC1_D3: R44.7, U1.79 (PC11), U13.14 (B2)
SPI1_MISO/QSPI1_IO1: U1.17 (PC2_C), U6.2 (SO(IO1))
SPI1_MOSI/QSPI1_IO0: U1.16 (PC1), U6.5 (SI(IO0))
SPI1_NSS/QSPI1_NSS: U1.41 (PE11), U6.1 (CE#)
SPI1_SCK/QSPI1_SCK: U1.25 (PA3), U6.6 (SCK)
SWCLK: J1.3, U1.76 (PA14(JTCK)
SWDIO: J1.2, U1.72 (PA13(JTMS)
UART1_CTS: U1.84 (PD3), U3.5 (A4Y)
UART1_RTS: U1.85 (PD4), U3.3 (A2)
UART1_RX: U1.87 (PD6), U3.4 (A3Y)
UART1_TX: U1.86 (PD5), U3.2 (A1)
USB_DFU_DN: R5.2, U1.70 (PA11)
USB_DFU_DP: R8.2, U1.71 (PA12)
WL_ON: R37.2, U1.93 (PB7), U2.9 (WL_REG_ON)
WP/QSPI1_IO2: U1.18 (PC3_C), U6.3 (WP(IO2))
Wi-Fi_CLK: R3.1, U2.20 (SDIO_CLK), U13.1 (A1)
Wi-Fi_CMD: U2.15 (SDIO_CMD), U13.6 (A5)
Wi-Fi_D0: U2.14 (SDIO_DATA0), U13.7 (A6)
Wi-Fi_D1: U2.16 (SDIO_DATA1), U13.5 (A4)
Wi-Fi_D2: U2.17 (SDIO_DATA2), U13.4 (A3)
Wi-Fi_D3: U2.18 (SDIO_DATA3), U13.3 (A2)

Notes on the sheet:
Type-2FY
LiPo
Level Shifter
1.8V
Wi-Fi
external falsh
STM-DFU
3.3V
MCU
HIF

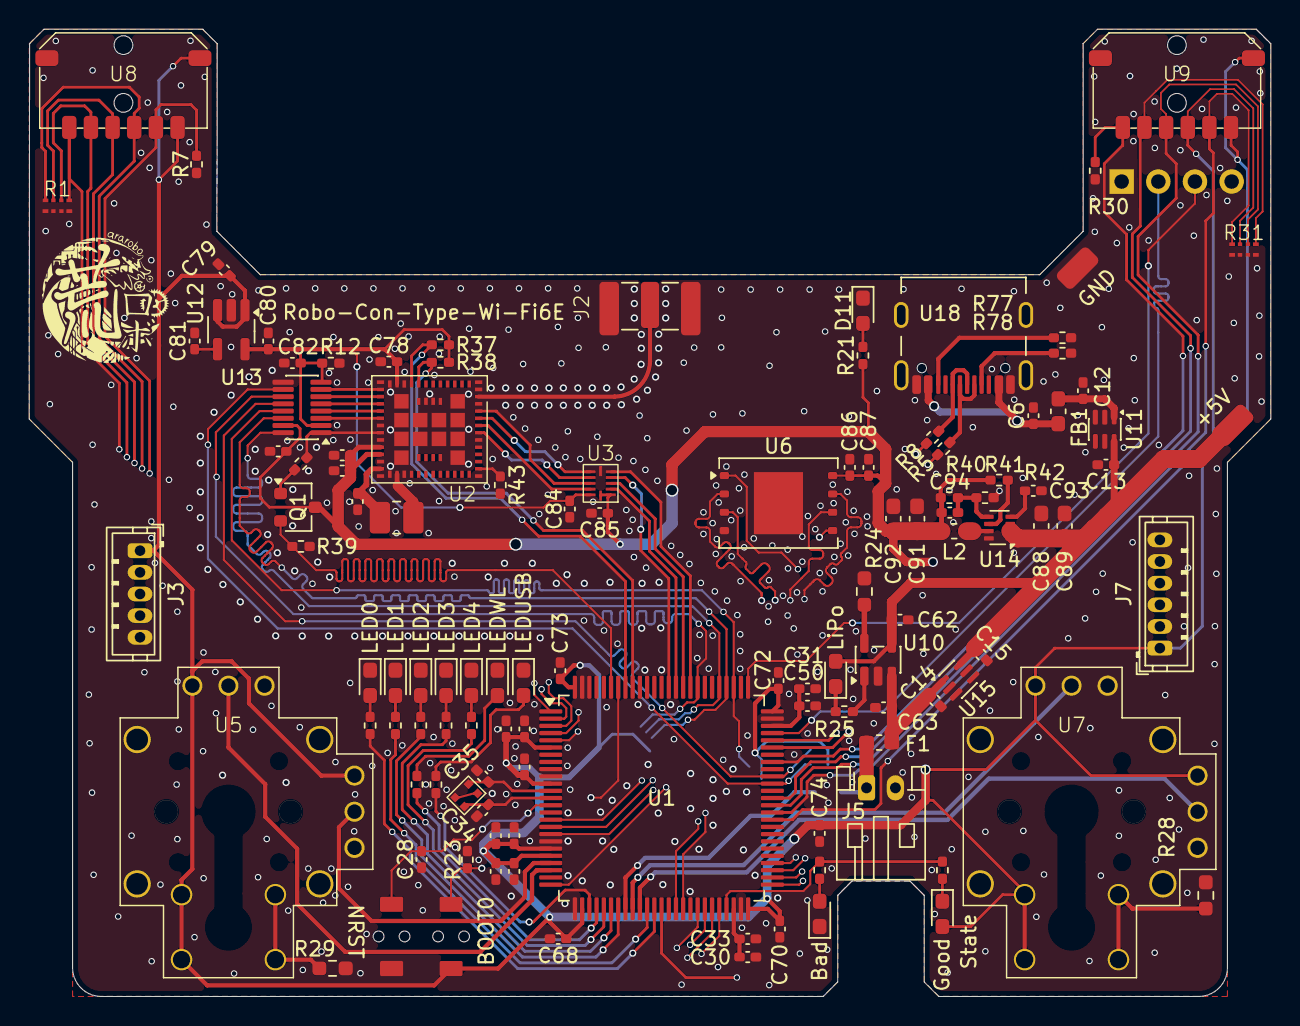
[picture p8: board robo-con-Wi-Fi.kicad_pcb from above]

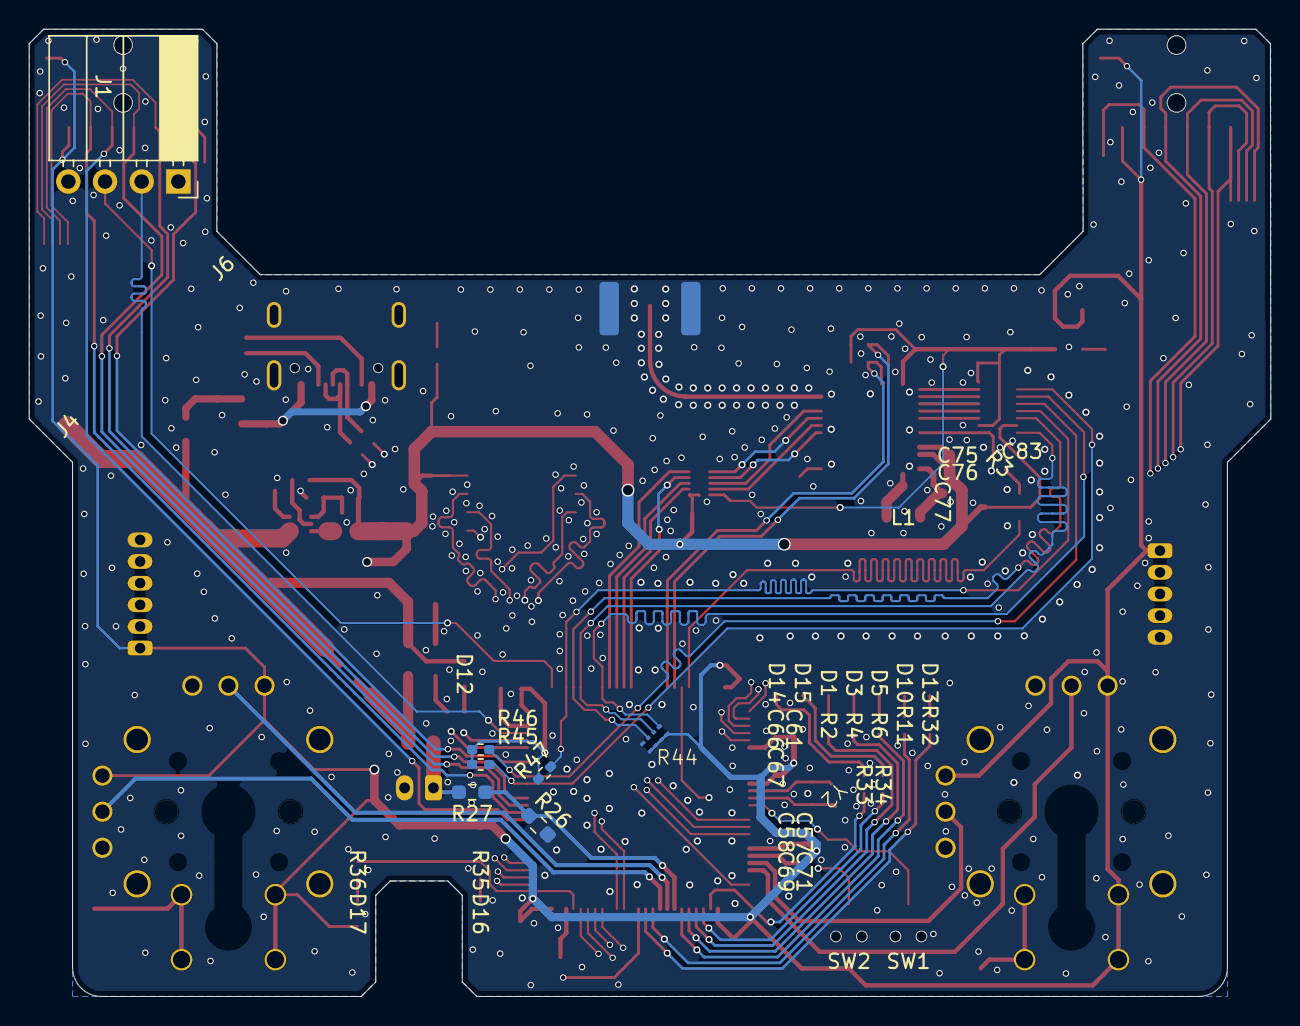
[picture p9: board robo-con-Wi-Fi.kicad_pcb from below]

Board: 4 copper layers, 86.0 x 67.0 mm, 124 parts (7 on the bottom side), 106 nets.

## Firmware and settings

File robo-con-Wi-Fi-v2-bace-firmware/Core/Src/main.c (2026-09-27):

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
/* Includes ------------------------------------------------------------------*/
#include "app_threadx.h"
#include "main.h"
#include "adc.h"
#include "dma.h"
#include "sdmmc.h"
#include "tim.h"
#include "usart.h"
#include "gpio.h"

/* USER CODE BEGIN Includes */
#include "app/robo-con.h"
#include <stdio.h>
#include "stm32_cyhal_sdio_ex.h"
#include "stm32_cyhal_gpio_ex.h"
#include "cyhal_system.h"
#include "cyhal_gpio.h"
#include "wifi_bt_if.h"
/* USER CODE END Includes */


void SystemClock_Config(void);
void PeriphCommonClock_Config(void);
static void MPU_Config(void);
/* USER CODE BEGIN 0 */
#define SDMMC_D0	PC8
#define SDMMC_D1	PC9
#define SDMMC_D2	PC10
#define SDMMC_D3	PC11
#define SDMMC_DATA_DELAY 10

void toggle_sdmmc_data(void)
{
    cyhal_gpio_init(SDMMC_D0, CYHAL_GPIO_DIR_OUTPUT,CYHAL_GPIO_DRIVE_PULLUP, false);
    cyhal_gpio_init(SDMMC_D1, CYHAL_GPIO_DIR_OUTPUT,CYHAL_GPIO_DRIVE_PULLUP, false);
    cyhal_gpio_init(SDMMC_D2, CYHAL_GPIO_DIR_OUTPUT,CYHAL_GPIO_DRIVE_PULLUP, false);
    cyhal_gpio_init(SDMMC_D3, CYHAL_GPIO_DIR_OUTPUT,CYHAL_GPIO_DRIVE_PULLUP, false);
    cyhal_system_delay_ms(SDMMC_DATA_DELAY);
    cyhal_gpio_write(SDMMC_D0, true);
    cyhal_gpio_write(SDMMC_D1, true);
    cyhal_gpio_write(SDMMC_D2, true);
    cyhal_gpio_write(SDMMC_D3, true);
    cyhal_system_delay_ms(SDMMC_DATA_DELAY);
    cyhal_gpio_free(SDMMC_D0);
    cyhal_gpio_free(SDMMC_D1);
    cyhal_gpio_free(SDMMC_D2);
    cyhal_gpio_free(SDMMC_D3);
}
/* USER CODE END 0 */

/**
  * @brief  The application entry point.
  * @retval int
  */
int main(void)
{

  /* MPU Configuration--------------------------------------------------------*/
  MPU_Config();

  /* Enable the CPU Cache */

  /* Enable I-Cache---------------------------------------------------------*/
  SCB_EnableICache();

  /* Enable D-Cache---------------------------------------------------------*/
  SCB_EnableDCache();

  /* MCU Configuration--------------------------------------------------------*/

  /* Reset of all peripherals, Initializes the Flash interface and the Systick. */
  HAL_Init();

  /* Configure the system clock */
  SystemClock_Config();

  /* Configure the peripherals common clocks */
  PeriphCommonClock_Config();

  /* Initialize all configured peripherals */
  MX_GPIO_Init();
  MX_DMA_Init();
  //MX_SDMMC1_SD_Init();
  MX_USART1_UART_Init();
  MX_USART3_UART_Init();
  MX_ADC1_Init();
  MX_ADC2_Init();
  MX_TIM6_Init();
  MX_TIM7_Init();
  /* USER CODE BEGIN 2 */

  toggle_sdmmc_data();

  /* Initialize sdio in stm32 cypal */
  hsd1.Instance = SDMMC1;
  if (stm32_cypal_wifi_sdio_init(&hsd1) != CY_RSLT_SUCCESS)
  {
    printf("\r\n    ERROR: Init failed\r\n\r\n");
    Error_Handler();
  }

  /* USER CODE END 2 */

  MX_ThreadX_Init();

  /* We should never get here as control is now taken by the scheduler */

  /* Infinite loop */
  /* USER CODE BEGIN WHILE */
  while (1)
  {
    /* USER CODE END WHILE */

    /* USER CODE BEGIN 3 */
  }
  /* USER CODE END 3 */
}

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
 /* MPU Configuration */

void MPU_Config(void)
{
  MPU_Region_InitTypeDef MPU_InitStruct = {0};

  /* Disables the MPU */
  HAL_MPU_Disable();

  /** Initializes and configures the Region and the memory to be protected
  */
  MPU_InitStruct.Enable = MPU_REGION_ENABLE;
  MPU_InitStruct.Number = MPU_REGION_NUMBER0;
  MPU_InitStruct.BaseAddress = 0x0;
  MPU_InitStruct.Size = MPU_REGION_SIZE_4GB;
  MPU_InitStruct.SubRegionDisable = 0x87;
  MPU_InitStruct.TypeExtField = MPU_TEX_LEVEL0;
  MPU_InitStruct.AccessPermission = MPU_REGION_NO_ACCESS;
  MPU_InitStruct.DisableExec = MPU_INSTRUCTION_ACCESS_DISABLE;
  MPU_InitStruct.IsShareable = MPU_ACCESS_SHAREABLE;
  MPU_InitStruct.IsCacheable = MPU_ACCESS_NOT_CACHEABLE;
  MPU_InitStruct.IsBufferable = MPU_ACCESS_NOT_BUFFERABLE;

  HAL_MPU_ConfigRegion(&MPU_InitStruct);
  /* Enables the MPU */
  HAL_MPU_Enable(MPU_PRIVILEGED_DEFAULT);

}

/**
  * @brief  Period elapsed callback in non blocking mode
  * @note   This function is called  when TIM1 interrupt took place, inside
  * HAL_TIM_IRQHandler(). It makes a direct call to HAL_IncTick() to increment
  * a global variable "uwTick" used as application time base.
  * @param  htim : TIM handle
  * @retval None
  */
void HAL_TIM_PeriodElapsedCallback(TIM_HandleTypeDef *htim)
{
  if (htim->Instance == TIM1)
  {
    HAL_IncTick();
  }
}

/**
  * @brief  This function is executed in case of error occurrence.
  * @retval None
  */
void Error_Handler(void)
{
  /* USER CODE BEGIN Error_Handler_Debug */
  /* User can add his own implementation to report the HAL error return state */
  __disable_irq();
  while (1)
  {
  }
  /* USER CODE END Error_Handler_Debug */
}
#ifdef USE_FULL_ASSERT
/**
  * @brief  Reports the name of the source file and the source line number
  *         where the assert_param error has occurred.
  * @param  file: pointer to the source file name
  * @param  line: assert_param error line source number
  * @retval None
  */
void assert_failed(uint8_t *file, uint32_t line)
{
  /* USER CODE BEGIN 6 */
  /* User can add his own implementation to report the file name and line number,
     ex: printf("Wrong parameters value: file %s on line %d\r\n", file, line) */
  /* USER CODE END 6 */
}
#endif /* USE_FULL_ASSERT */

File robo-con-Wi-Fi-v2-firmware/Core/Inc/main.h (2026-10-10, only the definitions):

#define LP_STICK_Pin GPIO_PIN_13
#define LP_STICK_GPIO_Port GPIOC
#define LEDWL_Pin GPIO_PIN_14
#define LEDWL_GPIO_Port GPIOC
#define LED2_Pin GPIO_PIN_15
#define LED2_GPIO_Port GPIOC
#define LEDWLRX_Pin GPIO_PIN_2
#define LEDWLRX_GPIO_Port GPIOC
#define LEDWLTX_Pin GPIO_PIN_3
#define LEDWLTX_GPIO_Port GPIOC
#define R1_BUTTON_Pin GPIO_PIN_7
#define R1_BUTTON_GPIO_Port GPIOA
#define R2_BUTTON_Pin GPIO_PIN_4
#define R2_BUTTON_GPIO_Port GPIOC
#define R3_BUTTON_Pin GPIO_PIN_5
#define R3_BUTTON_GPIO_Port GPIOC
#define R4_BUTTON_Pin GPIO_PIN_0
#define R4_BUTTON_GPIO_Port GPIOB
#define RP_STICK_Pin GPIO_PIN_1
#define RP_STICK_GPIO_Port GPIOB
#define R_PUSH_Pin GPIO_PIN_2
#define R_PUSH_GPIO_Port GPIOB
#define R_PUSH_HOME_Pin GPIO_PIN_10
#define R_PUSH_HOME_GPIO_Port GPIOB
#define LEDLiPo_Pin GPIO_PIN_12
#define LEDLiPo_GPIO_Port GPIOB
#define BT_ON_Pin GPIO_PIN_15
#define BT_ON_GPIO_Port GPIOB
#define WL_ON_Pin GPIO_PIN_6
#define WL_ON_GPIO_Port GPIOC
#define LED0_Pin GPIO_PIN_8
#define LED0_GPIO_Port GPIOA
#define LED1_Pin GPIO_PIN_15
#define LED1_GPIO_Port GPIOA
#define LEDUSB_Pin GPIO_PIN_3
#define LEDUSB_GPIO_Port GPIOB
#define L8_BUTTON_Pin GPIO_PIN_4
#define L8_BUTTON_GPIO_Port GPIOB
#define L7_BUTTON_Pin GPIO_PIN_5
#define L7_BUTTON_GPIO_Port GPIOB
#define L6_BUTTON_Pin GPIO_PIN_6
#define L6_BUTTON_GPIO_Port GPIOB
#define L5_BUTTON_Pin GPIO_PIN_7
#define L5_BUTTON_GPIO_Port GPIOB
#define L_PUSH_HOME_Pin GPIO_PIN_8
#define L_PUSH_HOME_GPIO_Port GPIOB
#define L_PUSH_Pin GPIO_PIN_9
#define L_PUSH_GPIO_Port GPIOB

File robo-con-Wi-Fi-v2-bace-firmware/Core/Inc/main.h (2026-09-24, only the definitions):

#define L0_LEVER_Pin GPIO_PIN_2
#define L0_LEVER_GPIO_Port GPIOE
#define L2_LEVER_Pin GPIO_PIN_3
#define L2_LEVER_GPIO_Port GPIOE
#define L1_LEVER_Pin GPIO_PIN_4
#define L1_LEVER_GPIO_Port GPIOE
#define L3_LEVER_Pin GPIO_PIN_5
#define L3_LEVER_GPIO_Port GPIOE
#define L4_LEVER_Pin GPIO_PIN_6
#define L4_LEVER_GPIO_Port GPIOE
#define L5_BUTTON_Pin GPIO_PIN_13
#define L5_BUTTON_GPIO_Port GPIOC
#define L6_BUTTON_Pin GPIO_PIN_14
#define L6_BUTTON_GPIO_Port GPIOC
#define L7_BUTTON_Pin GPIO_PIN_15
#define L7_BUTTON_GPIO_Port GPIOC
#define L8_BUTTON_Pin GPIO_PIN_0
#define L8_BUTTON_GPIO_Port GPIOC
#define LY_STICK_Pin GPIO_PIN_4
#define LY_STICK_GPIO_Port GPIOA
#define LX_STICK_Pin GPIO_PIN_5
#define LX_STICK_GPIO_Port GPIOA
#define LP_STICK_Pin GPIO_PIN_6
#define LP_STICK_GPIO_Port GPIOA
#define LiPo_OBSERVE_Pin GPIO_PIN_5
#define LiPo_OBSERVE_GPIO_Port GPIOC
#define RX_STICK_Pin GPIO_PIN_0
#define RX_STICK_GPIO_Port GPIOB
#define RY_STICK_Pin GPIO_PIN_1
#define RY_STICK_GPIO_Port GPIOB
#define RP_STICK_Pin GPIO_PIN_11
#define RP_STICK_GPIO_Port GPIOB
#define R1_BUTTON_Pin GPIO_PIN_12
#define R1_BUTTON_GPIO_Port GPIOB
#define R2_BUTTON_Pin GPIO_PIN_13
#define R2_BUTTON_GPIO_Port GPIOB
#define R3_BUTTON_Pin GPIO_PIN_14
#define R3_BUTTON_GPIO_Port GPIOB
#define R4_BUTTON_Pin GPIO_PIN_15
#define R4_BUTTON_GPIO_Port GPIOB
#define R4_LEVER_Pin GPIO_PIN_10
#define R4_LEVER_GPIO_Port GPIOD
#define R3_LEVER_Pin GPIO_PIN_13
#define R3_LEVER_GPIO_Port GPIOD
#define R0_LEVER_Pin GPIO_PIN_14
#define R0_LEVER_GPIO_Port GPIOD
#define R2_LEVER_Pin GPIO_PIN_15
#define R2_LEVER_GPIO_Port GPIOD
#define R1_LEVER_Pin GPIO_PIN_6
#define R1_LEVER_GPIO_Port GPIOC
#define WL_ON_Pin GPIO_PIN_5
#define WL_ON_GPIO_Port GPIOD
#define BT_ON_Pin GPIO_PIN_6
#define BT_ON_GPIO_Port GPIOD
#define LED0_Pin GPIO_PIN_3
#define LED0_GPIO_Port GPIOB
#define LED1_Pin GPIO_PIN_4
#define LED1_GPIO_Port GPIOB
#define LED2_Pin GPIO_PIN_5
#define LED2_GPIO_Port GPIOB
#define LED3_Pin GPIO_PIN_6
#define LED3_GPIO_Port GPIOB
#define LED4_Pin GPIO_PIN_7
#define LED4_GPIO_Port GPIOB
#define LEDWL_Pin GPIO_PIN_8
#define LEDWL_GPIO_Port GPIOB
#define LEDUSB_Pin GPIO_PIN_9
#define LEDUSB_GPIO_Port GPIOB
#define LEDLiPo_GOOD_Pin GPIO_PIN_0
#define LEDLiPo_GOOD_GPIO_Port GPIOE
#define LEDLiPo_BAD_Pin GPIO_PIN_1
#define LEDLiPo_BAD_GPIO_Port GPIOE

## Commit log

2026-08-17 部品選定
    [robo-con-Wi-Fi.kicad_pcb, robo-con-Wi-Fi.kicad_sch]
2026-08-18 RF部の配線
    [robo-con-Wi-Fi.kicad_pcb, robo-con-Wi-Fi.kicad_sch]
2026-08-19 電源周りの部品構成完了
    [robo-con-Wi-Fi.kicad_pcb, robo-con-Wi-Fi.kicad_sch]
2026-08-23 LEDを置く位置が微妙い
    [robo-con-Wi-Fi.kicad_pcb]
2026-08-23 LiPo監視用ADCとLED追加
    [robo-con-Wi-Fi.kicad_pcb, robo-con-Wi-Fi.kicad_sch]
2026-08-24 フットプリントを配置残り配線と配線長合わせ
    [robo-con-Wi-Fi.kicad_pcb, robo-con-Wi-Fi.kicad_sch]
2026-08-24 PCB配線した 長さ合わせた後確認
    [robo-con-Wi-Fi.kicad_pcb, robo-con-Wi-Fi.kicad_sch]
2026-08-24 ほぼ完成
    [robo-con-Wi-Fi.kicad_pcb, robo-con-Wi-Fi.kicad_sch]
2026-08-25 sdioのプルアップ追加
    [robo-con-Wi-Fi.kicad_pcb, robo-con-Wi-Fi.kicad_sch]
2026-08-25 ガーバー出力
    [bom.csv, designators.csv, positions.csv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]
2026-08-25 ビアの穴径を修正
    [robo-con-Wi-Fi.kicad_pcb]
2026-08-25 M2穴追加
    [designators.csv, positions.csv, robo-con-Wi-Fi.kicad_pcb]
2026-08-25 ピンの位置ずれ
    [robo-con-Wi-Fi.kicad_sch]
2026-09-22 部品の構成と電源の構成の作成
    [robo-con-Wi-Fi-v2.kicad_pcb, robo-con-Wi-Fi-v2.kicad_sch]
2026-09-23 v2 配線
    [robo-con-Wi-Fi-v2.kicad_pcb, robo-con-Wi-Fi-v2.kicad_sch]
2026-09-23 一応 配線とシルク完了
    [robo-con-Wi-Fi-v2.kicad_pcb]
2026-09-24 firmwareのファイル名を変更
2026-09-24 v1のテストコードを追加
2026-09-26 feat メモリー関数のblx
2026-09-26 HEADを統合
2026-09-30 move v2 program file & update PCB
    [robo-con-Wi-Fi-v2.kicad_pcb, robo-con-Wi-Fi-v2.kicad_sch]
2026-10-01 update PCB
    [robo-con-Wi-Fi-v2.kicad_pcb, robo-con-Wi-Fi-v2.kicad_sch]
2026-10-07 pcb size
    [robo-con-Wi-Fi-v2.kicad_pcb]
2026-10-10 new firmware from STM32H723 to STM32H7A3
2026-10-10 link submodule
    [robo-con-Wi-Fi-v2.kicad_pcb]
2026-10-27 3.3v - > 1.8v
2026-10-27 スレッドの確認

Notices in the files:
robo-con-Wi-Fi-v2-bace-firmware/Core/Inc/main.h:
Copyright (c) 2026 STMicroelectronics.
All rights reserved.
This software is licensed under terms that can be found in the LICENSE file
